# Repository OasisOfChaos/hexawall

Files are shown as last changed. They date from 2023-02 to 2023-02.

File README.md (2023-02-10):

<!-- Improved compatibility of back to top link: See: https://github.com/othneildrew/Best-README-Template/pull/73 -->

<!-- PROJECT LOGO -->
<br />
<div align="center">
  <a href="https://github.com/OasisOfChaos/hexawall">
    
  </a>

<h3 align="center">HexaWall</h3>

  <p align="center">
    <a href="https://github.com/OasisOfChaos/hexawall">GitHub page</a>
  </p>
</div>

<!-- ABOUT THE PROJECT -->
## About The Project

### A pretty big ESP32-driven LED thing for on your wall with about 60 'sequences' you can control via MQTT. 

[Product Name Screen Shot](https://github.com/OasisOfChaos/hexawall)

The dimensions of the thing in this pic are about 1.7m by 0.7m but you can make it as large or small as you'd like.

This repo contains all the different projects to make this thing yourself:
* (PlatformIO) ESP32 firmware (this is a framework with plugin-based 'sequences')
* (Autodesk Inventor) 3D files to print the hexagons
* (Eagle) PCB files
* (Dotnet-Core 6 Blazor) website to control the thing

### Some remarks
* Every hexagon has 30 LEDS.
* I used 12VDC WS2815B ledstrips (BTF-Lighting) but because I used the FastLED library you can use a lot of other addressable strips. 
* I soldered them with separate wires but I'd advice to use the solderless connectors instead. Much easier. You may have to enlarge the hexagon a bit for this though.
* Although the PCB has a provision for powering the ESP I could not get that part to work. Maybe a timing problem or just the power supply I used (a 12V16A supply from AliExpress). In the end I just used a separate power adapter to power the ESP via USB.
* Power the LEDS from TWO sides with a wire large enough for 12VDC/8A. I used 2.5mm2 but it can probably be a bit smaller.
* Some of the sequences are made for this layout specifically. You can follow this one or just remove/rewrite the appropriate sequences.
* The hexagon 'covers' are 3mm acrylate sheets, laser cut.
* Yes, I drilled holes in my wall for the wires and control stuff.

### All this is provided as-is. I will not be able to contribute to this project in the future. Use what you like!

### A Reddit post contains some extra info: (https://www.reddit.com/r/FastLED/comments/10ue1d8/my_hexawall_project/)

<p align="right">(<a href="#readme-top">back to top</a>)</p>

<!-- MARKDOWN LINKS & IMAGES -->
<!-- https://www.markdownguide.org/basic-syntax/#reference-style-links -->
[contributors-shield]: https://img.shields.io/github/contributors/github_username/repo_name.svg?style=for-the-badge
[contributors-url]: https://github.com/github_username/repo_name/graphs/contributors
[forks-shield]: https://img.shields.io/github/forks/github_username/repo_name.svg?style=for-the-badge
[forks-url]: https://github.com/github_username/repo_name/network/members
[stars-shield]: https://img.shields.io/github/stars/github_username/repo_name.svg?style=for-the-badge
[stars-url]: https://github.com/github_username/repo_name/stargazers
[issues-shield]: https://img.shields.io/github/issues/github_username/repo_name.svg?style=for-the-badge
[issues-url]: https://github.com/github_username/repo_name/issues
[license-shield]: https://img.shields.io/github/license/github_username/repo_name.svg?style=for-the-badge
[license-url]: https://github.com/github_username/repo_name/blob/master/LICENSE.txt
[linkedin-shield]: https://img.shields.io/badge/-LinkedIn-black.svg?style=for-the-badge&logo=linkedin&colorB=555
[linkedin-url]: https://linkedin.com/in/linkedin_username
[product-screenshot]: https://github.com/OasisOfChaos/hexawall/blob/main/Images/demo.gif
[Next.js]: https://img.shields.io/badge/next.js-000000?style=for-the-badge&logo=nextdotjs&logoColor=white
[Next-url]: https://nextjs.org/
[React.js]: https://img.shields.io/badge/React-20232A?style=for-the-badge&logo=react&logoColor=61DAFB
[React-url]: https://reactjs.org/
[Vue.js]: https://img.shields.io/badge/Vue.js-35495E?style=for-the-badge&logo=vuedotjs&logoColor=4FC08D
[Vue-url]: https://vuejs.org/
[Angular.io]: https://img.shields.io/badge/Angular-DD0031?style=for-the-badge&logo=angular&logoColor=white
[Angular-url]: https://angular.io/
[Svelte.dev]: https://img.shields.io/badge/Svelte-4A4A55?style=for-the-badge&logo=svelte&logoColor=FF3E00
[Svelte-url]: https://svelte.dev/
[Laravel.com]: https://img.shields.io/badge/Laravel-FF2D20?style=for-the-badge&logo=laravel&logoColor=white
[Laravel-url]: https://laravel.com
[Bootstrap.com]: https://img.shields.io/badge/Bootstrap-563D7C?style=for-the-badge&logo=bootstrap&logoColor=white
[Bootstrap-url]: https://getbootstrap.com
[JQuery.com]: https://img.shields.io/badge/jQuery-0769AD?style=for-the-badge&logo=jquery&logoColor=white
[JQuery-url]: https://jquery.com

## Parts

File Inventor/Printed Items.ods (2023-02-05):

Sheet: Sheet1
Item | Required | Printed | Remaining
Cover v1 - 175 - 12mm rim | 25 | 19 | 6
Base v6 - 175 | 25 | 25 | 0
Flat Placeholder v1 - 175 - 12mm rim - A | 7 | 7 | 0
Flat Placeholder v1 - 175 - 12mm rim - B | 7 | 6 | 1 | 1 damaged

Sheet: Sheet2
1 | 2 | 3 | 4 | 5 | 6 | 7 | 8 | 9
10 | 11 | 12 | 13 | 14 | 15 | 16 | 17 | 18
19 | 20 | 21 | 22 | 23 | 24 | 25 | 26 | 27
1 | 2 | 3 | 4 | 5 | 6 | 7 | 8 | 9
10 | 11 | 12 | 13 | 14 | 15 | 16 | 17 | 18
19 | 20 | 21 | 22 | 23 | 24 | 25 | 26 | 27

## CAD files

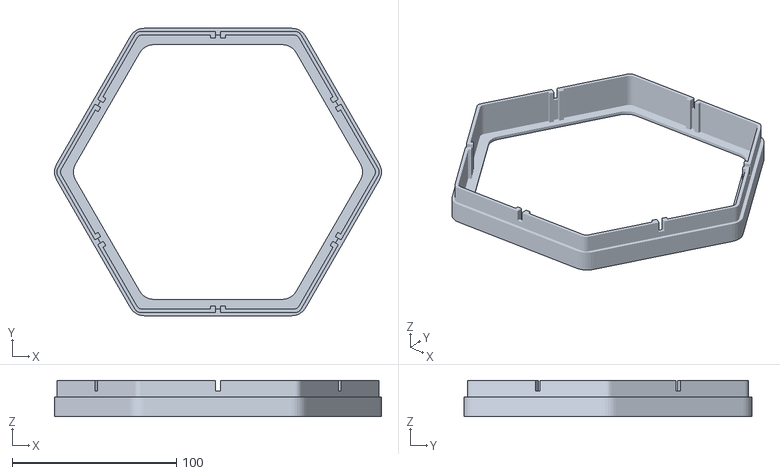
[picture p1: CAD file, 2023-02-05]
Inventor/Cover Adapter v1 - 175.stl
199.0 x 175.0 x 22.0

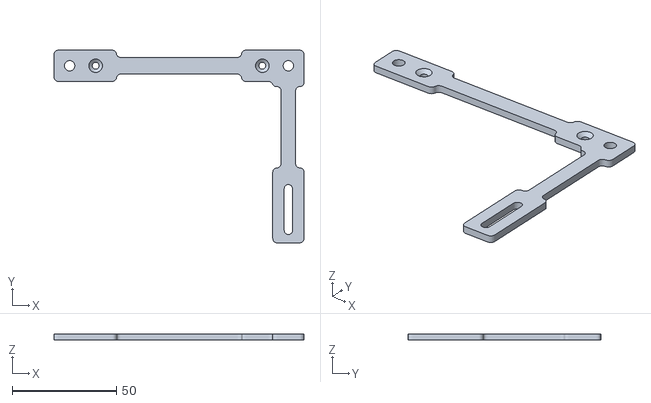
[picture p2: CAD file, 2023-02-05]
Inventor/pcb/Power Supply Wall Mount v3.stl
120.0 x 92.5 x 3.00

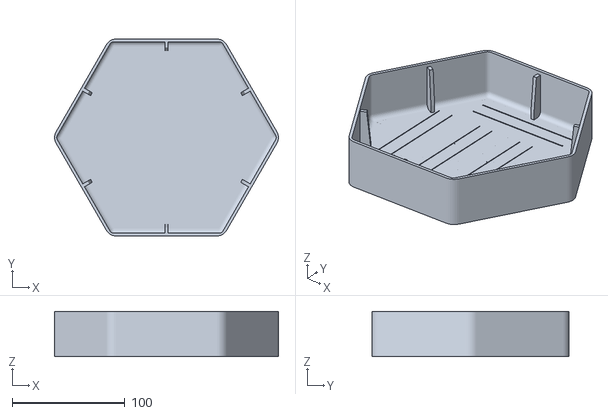
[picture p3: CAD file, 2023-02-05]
Inventor/Base v6 - 175 - thicker wall.stl
199.0 x 175.0 x 40.0

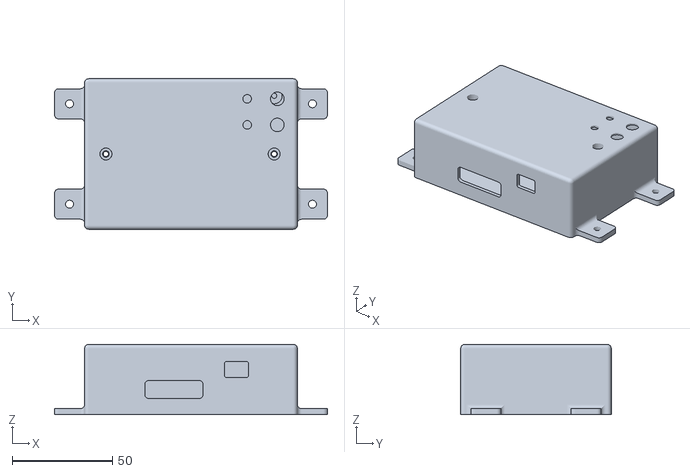
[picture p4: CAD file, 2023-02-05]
Inventor/pcb/Enclosure v1.stl
136.0 x 75.0 x 35.0

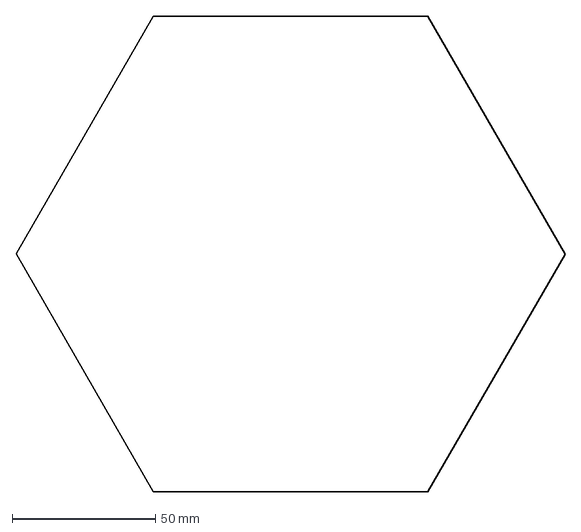
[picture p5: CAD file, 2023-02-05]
Inventor/Frosted Top v1 - 175.dxf
191.7 x 166.0 mm

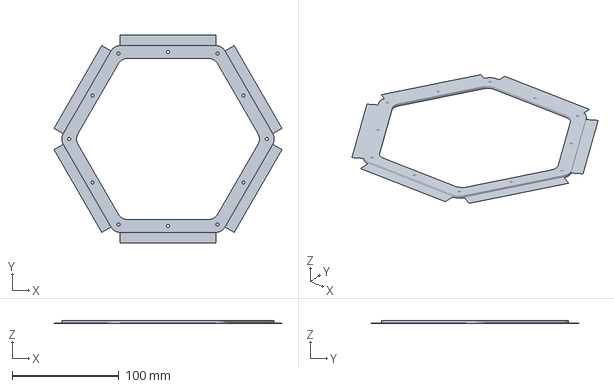
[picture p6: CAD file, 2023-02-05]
Inventor/Flat Placeholder v1 - 175 - 12mm rim.3mf
213.6 x 195.0 x 2.50 mm

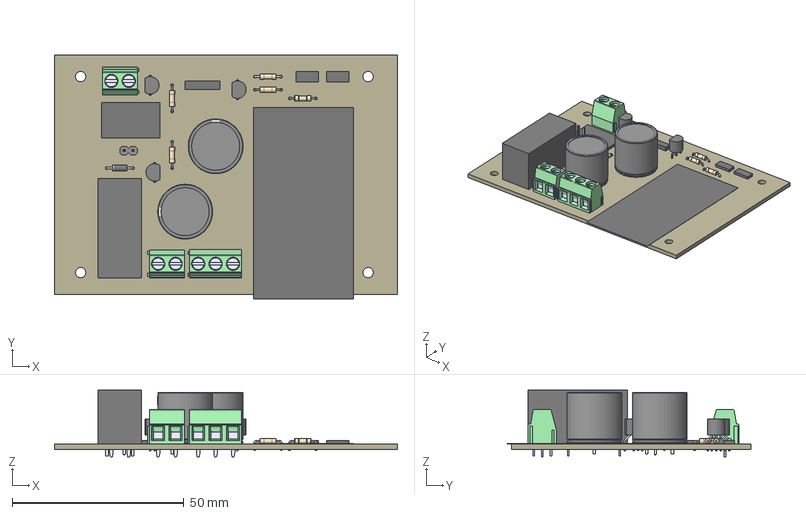
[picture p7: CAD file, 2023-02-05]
Inventor/pcb/HexaWall-v1.1 v7.step
100.0 x 71.2 x 19.5 mm
Board
F/CM12P
DO35-7
DRILEGEND
1X02
G5RL-1-E-HR
0204/7 x 5
DC/DC_PCB
TO92-CBE x 3
E7,5-16 x 2
TB006-508-02P_Green - S
ESP32-DEVKITV1
TB006-508-02P_Green - S (1)
TB006-508-03P_Green - S

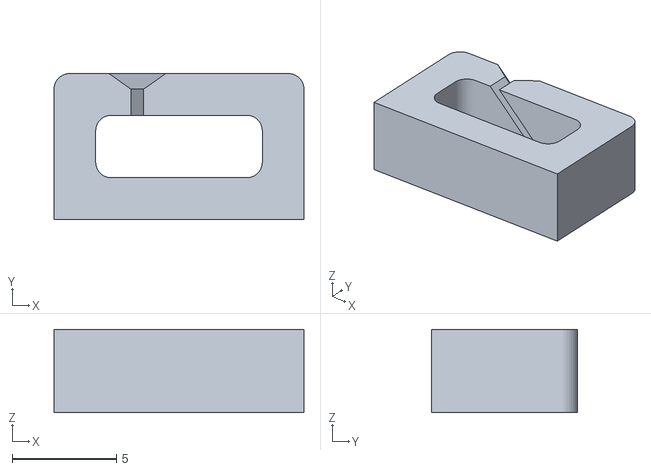
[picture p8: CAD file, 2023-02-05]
Inventor/Cable Clip v3.stl
12.0 x 7.00 x 4.00

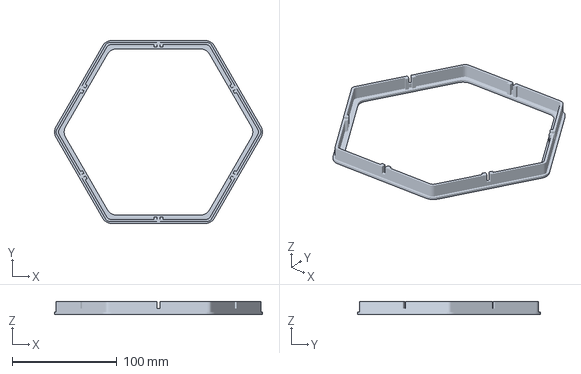
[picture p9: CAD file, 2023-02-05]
Inventor/Cover v1 - 175 - 8mm rim.3mf
199.0 x 175.0 x 12.0 mm

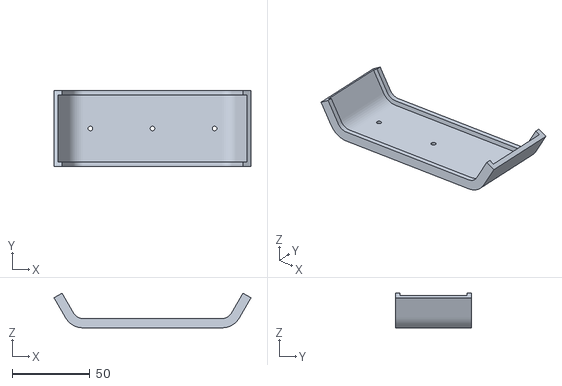
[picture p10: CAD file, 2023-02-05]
Inventor/Drill Helper v1.stl
126.8 x 49.0 x 22.3

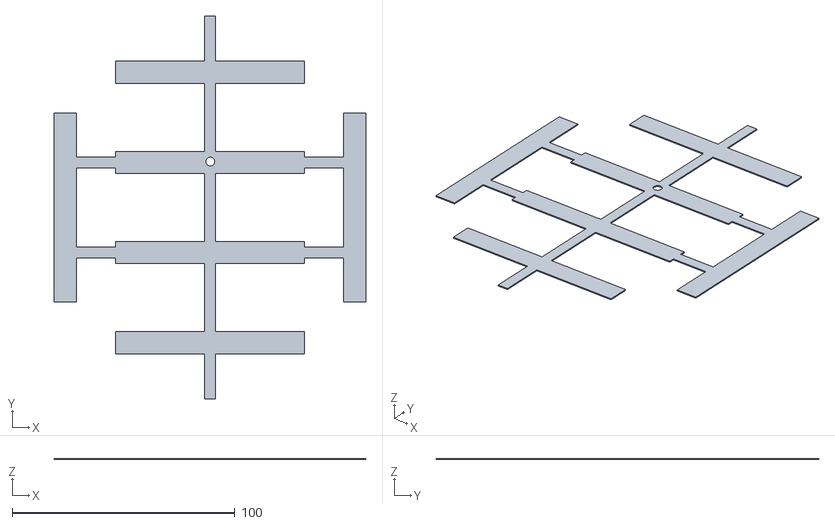
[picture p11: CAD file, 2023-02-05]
Inventor/LED Grid v1.stl
140.0 x 172.0 x 0.5

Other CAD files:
Inventor/Wall Assembly 1600 - 175 - 23 pieces.dwg
Inventor/Wall Assembly 1600 - 175 - 25 pieces - Wall 2 - version A - 0-based.dwg
Inventor/Wall Assembly 1600 - 175 - 25 pieces - version B.dwg
Inventor/Wall Assembly 1600 - 175 - 25 pieces - Wall 2 - version A-.dwg
Inventor/Frosted Top Cutting Helper.dwg
Inventor/Base v6 - 175.stl
Inventor/Paper Cutout v1.dwg
Inventor/Aligner Helper Assembly.iam
Inventor/Aligner Helper v1.ipt
Inventor/Aligner Helper v1.stl
Inventor/Aligner Helper v2.ipt
Inventor/Aligner Helper v2.stl
Inventor/Aligner Helper v3.ipt
Inventor/Aligner Helper v3.stl
Inventor/Base v1 - 150.ipt
Inventor/Base v1.ipt
Inventor/Base v2.ipt
Inventor/Base v3 - 175.ipt
Inventor/Base v3.ipt
Inventor/Base v4 - 175.ipt
Inventor/Base v5 - 175.ipt
Inventor/Base v6 - 175 - thicker wall - Copy.ipt
Inventor/Base v6 - 175 - thicker wall.ipt
Inventor/Base v6 - 175.ipt
Inventor/Base v6 - 88.ipt
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

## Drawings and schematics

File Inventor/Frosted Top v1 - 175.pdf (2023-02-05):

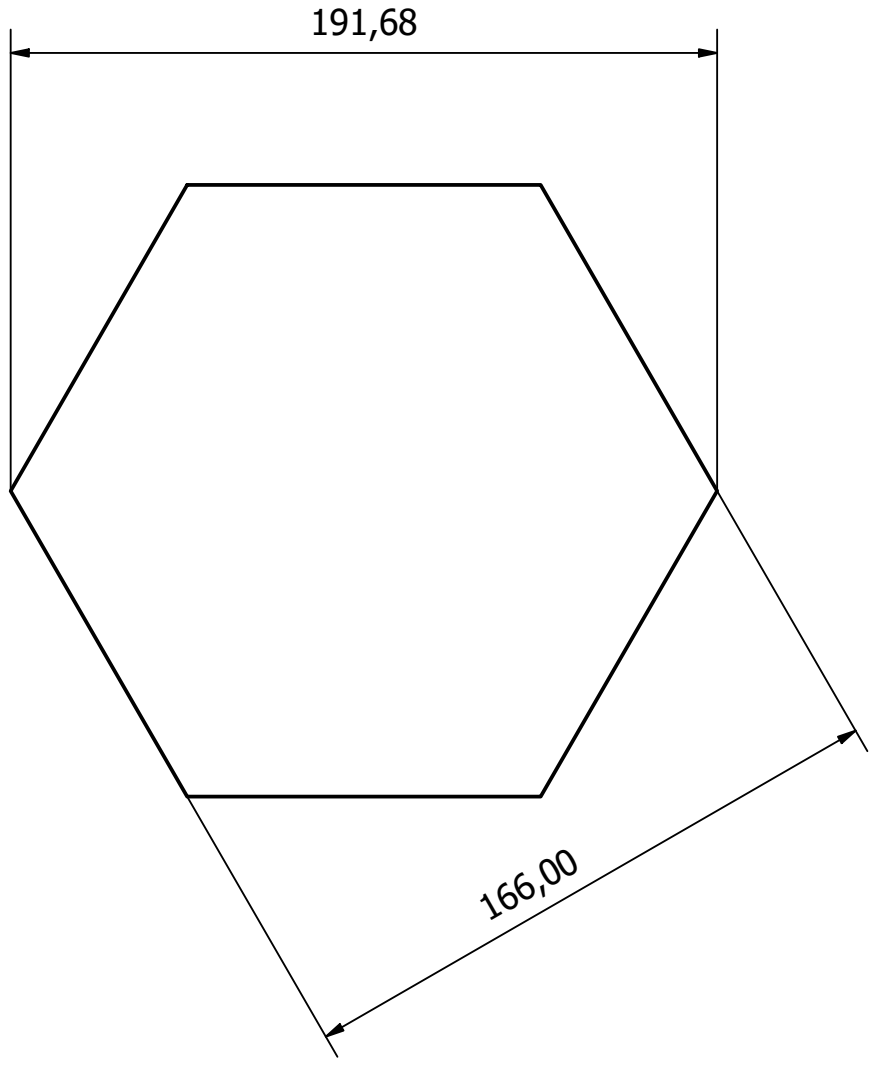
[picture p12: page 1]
Designed by; Checked by; Approved by; Date

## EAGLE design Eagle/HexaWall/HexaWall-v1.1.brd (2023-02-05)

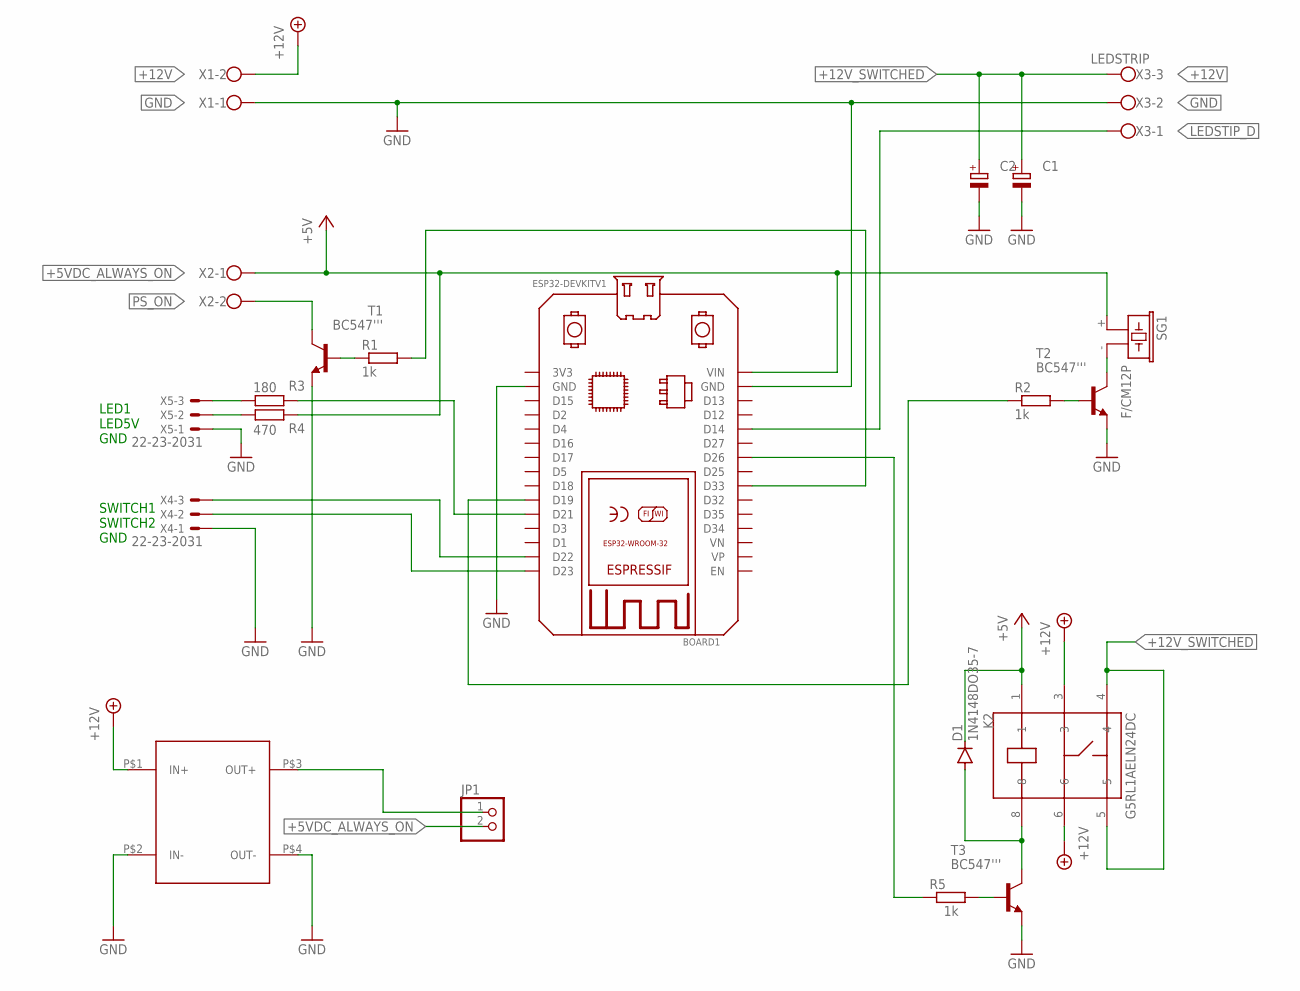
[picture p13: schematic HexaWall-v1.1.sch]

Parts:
BOARD1: ESP32DEVKITV1; ESP32-DEVKITV1
C1, C2: CPOL-EUE7.5-16; E7,5-16
D1: 1N4148DO35-7; DO35-7
JP1: PINHD-1X2; 1X02
K2: G5RL1AELN24DC; G5RL-1-E-HR
PS$1: DC/DC_PCB
R1, R2, R5: 1k; 0204/7
R3: 180; 0204/7
R4: 470; 0204/7
SG1: F/CM12P
T1, T2, T3: BC547'''; TO92-CBE
X1, X2: W237-102
X3: LEDSTRIP; W237-103
X4, X5: 22-23-2031

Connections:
+5VDC_ALWAYS_ON: BOARD1.VIN, D1.C, JP1.2, K2.1, R4.1, SG1.+ (1), X2.1
+12V: K2.3, K2.6, PS$1.P$1 (IN+), X1.2
+12V_SWITCHED: C1.+, C2.+, K2.4, K2.5, X3.3
GND: BOARD1.GND, C1.-, C2.-, PS$1.P$2 (IN-), PS$1.P$4 (OUT-), T1.E, T2.E, T3.E, X1.1, X3.2, X4.1, X5.1
LEDSTIP_D: BOARD1.D14, X3.1
unnamed: R5.2, T3.B
unnamed: R4.2, X5.2
unnamed: R2.2, T2.B
unnamed: BOARD1.D19, R2.1
unnamed: R1.1, T1.B
unnamed: BOARD1.D33, R1.2
unnamed: R3.2, X5.3
unnamed: D1.A, K2.8, T3.C
unnamed: BOARD1.D26, R5.1
unnamed: SG1.- (2), T2.C
unnamed: JP1.1, PS$1.P$3 (OUT+)
unnamed: BOARD1.D22, X4.3
unnamed: BOARD1.D23, X4.2
unnamed: BOARD1.D21, R3.1
PS_ON: T1.C, X2.2

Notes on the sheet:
LED1 LED5V GND
SWITCH1 SWITCH2 GND

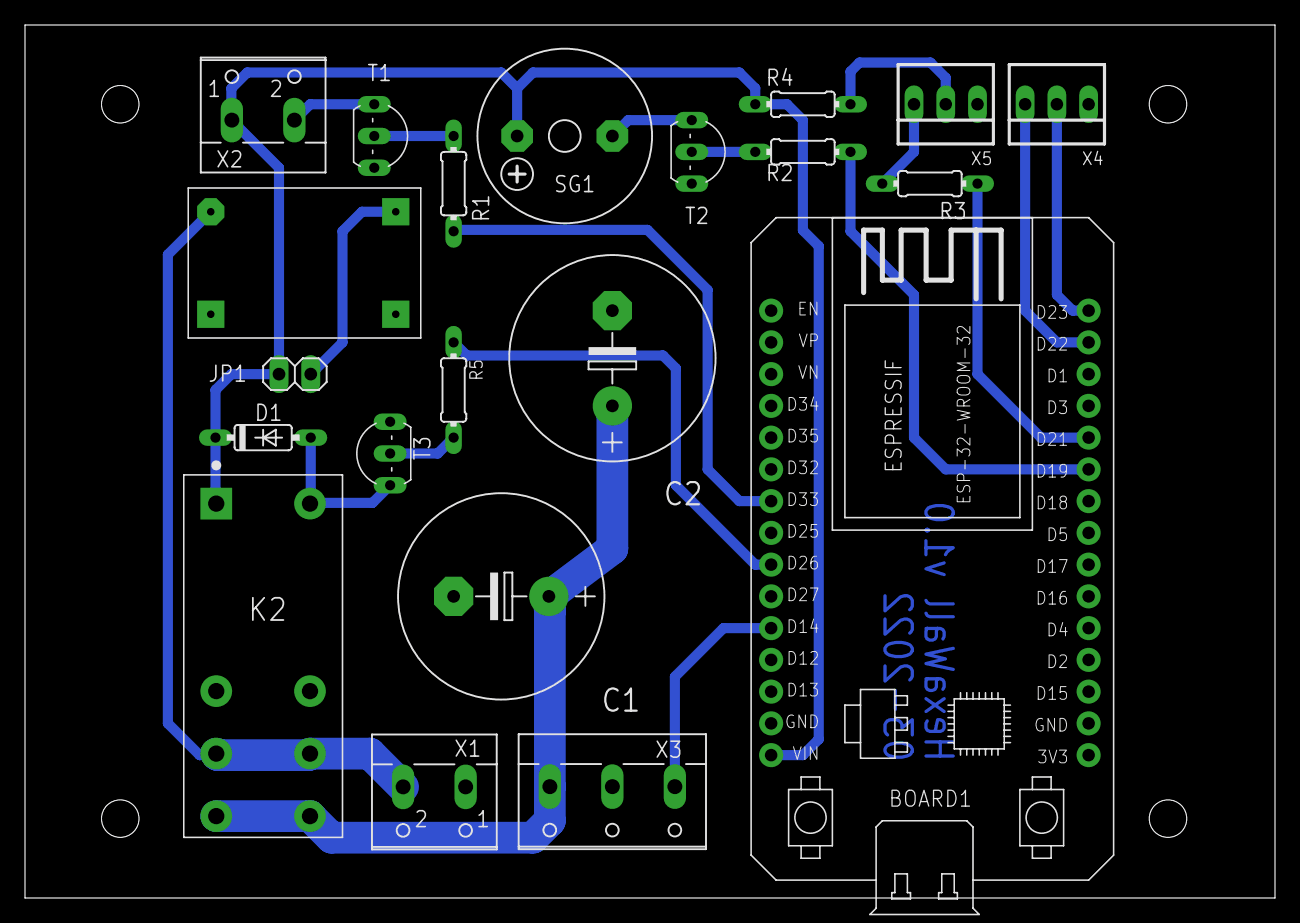
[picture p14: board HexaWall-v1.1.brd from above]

Board: 2 copper layers, 100.0 x 69.8 mm, 22 parts (0 on the bottom side), 20 nets.

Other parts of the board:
DRILEGEND: DRILEGEND

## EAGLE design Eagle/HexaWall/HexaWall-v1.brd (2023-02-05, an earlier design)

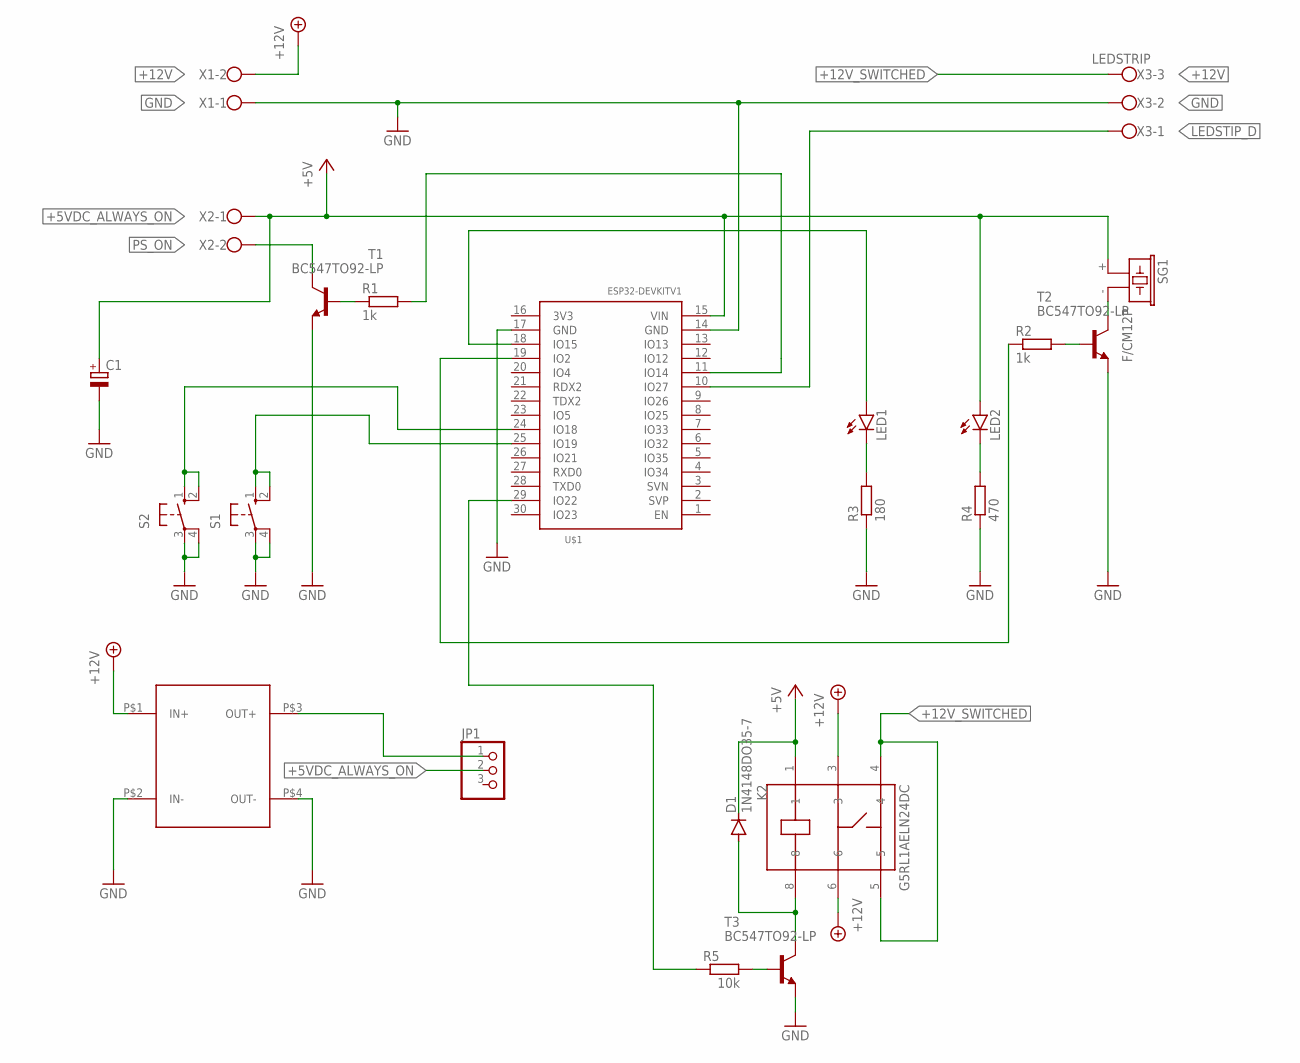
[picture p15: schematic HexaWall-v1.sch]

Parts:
C1: CPOL-EUE10-20; EB20D
D1: 1N4148DO35-7; DO35-7
JP1: PINHD-1X3; 1X03
K2: G5RL1AELN24DC; G5RL-1-E-HR
LED1, LED2: LED5MM
PS$1: DC/DC_PCB
R1, R2: 1k; 0204/7
R3: 180; 0204/7
R4: 470; 0204/7
R5: 10k; 0204/7
S1, S2: 40-XX; B3F-40XX
SG1: F/CM12P
T1, T2, T3: BC547TO92-LP; TO92-CBE
U$1: ESP32DEVKITV1; ESP32-DEVKITV1
X1, X2: W237-102
X3: LEDSTRIP; W237-103

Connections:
+5VDC_ALWAYS_ON: C1.+, D1.C, JP1.2, K2.1, LED2.A, SG1.+ (1), U$1.15 (VIN), X2.1
+12V: K2.3, K2.6, PS$1.P$1 (IN+), X1.2
+12V_SWITCHED: K2.4, K2.5, X3.3
GND: C1.-, PS$1.P$2 (IN-), PS$1.P$4 (OUT-), R3.1, R4.1, S1.3, S1.4 (P1), S2.3, S2.4 (P1), T1.E, T2.E, T3.E, U$1.14 (GND), U$1.17 (GND), X1.1, X3.2
LEDSTIP_D: U$1.10 (IO27), X3.1
unnamed: R5.2, T3.B
unnamed: LED1.K (C), R3.2
unnamed: R2.2, T2.B
unnamed: R2.1, U$1.19 (IO2)
unnamed: R1.1, T1.B
unnamed: R1.2, U$1.11 (IO14)
unnamed: LED2.K (C), R4.2
unnamed: D1.A, K2.8, T3.C
unnamed: R5.1, U$1.29 (IO22)
unnamed: SG1.- (2), T2.C
unnamed: LED1.A, U$1.18 (IO15)
unnamed: JP1.1, PS$1.P$3 (OUT+)
OTA_BUTTON: S2.1 (S), S2.2 (S1), U$1.24 (IO18)
POWER_BUTTON: S1.1 (S), S1.2 (S1), U$1.25 (IO19)
PS_ON: T1.C, X2.2

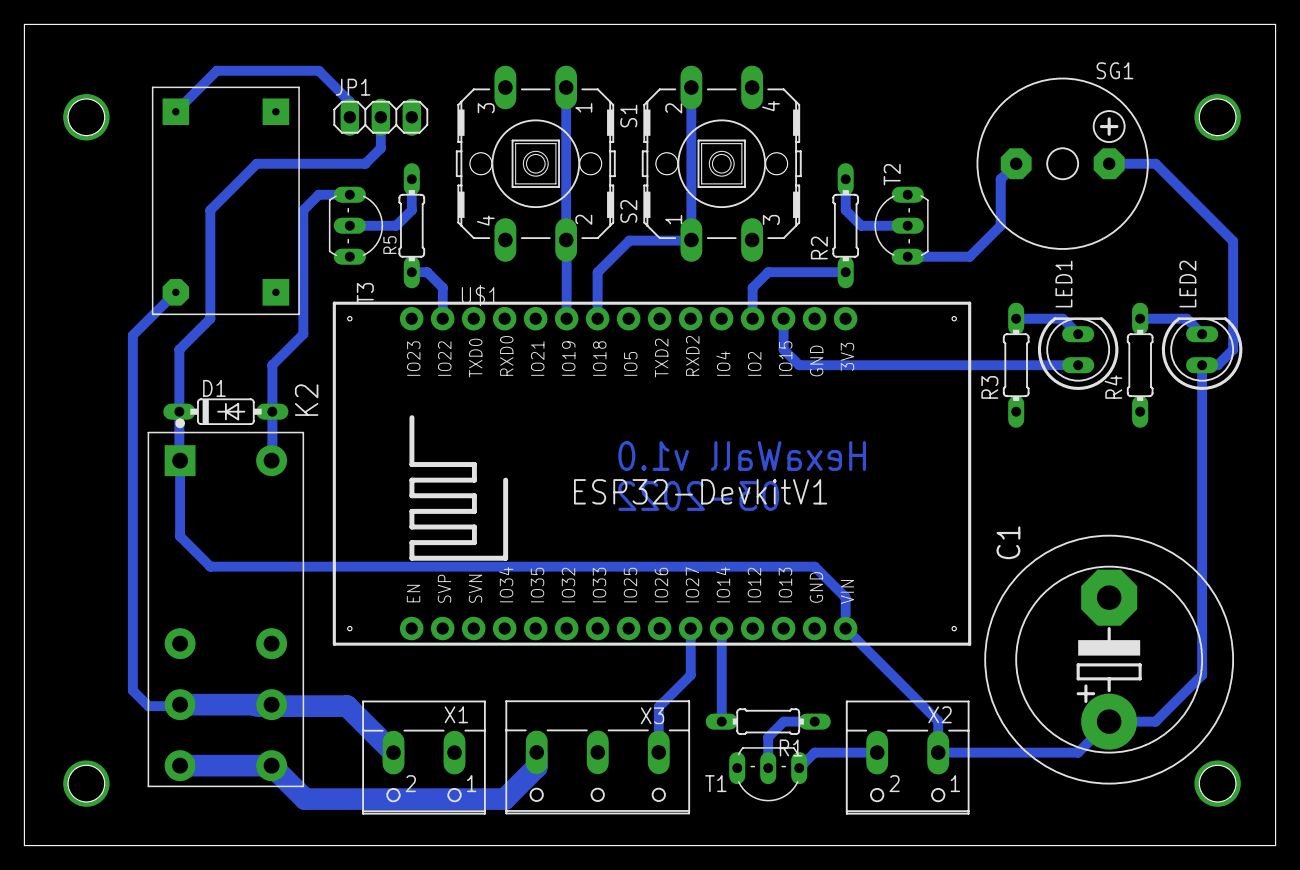
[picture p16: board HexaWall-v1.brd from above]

Board: 2 copper layers, 102.5 x 67.3 mm, 22 parts (0 on the bottom side), 20 nets.

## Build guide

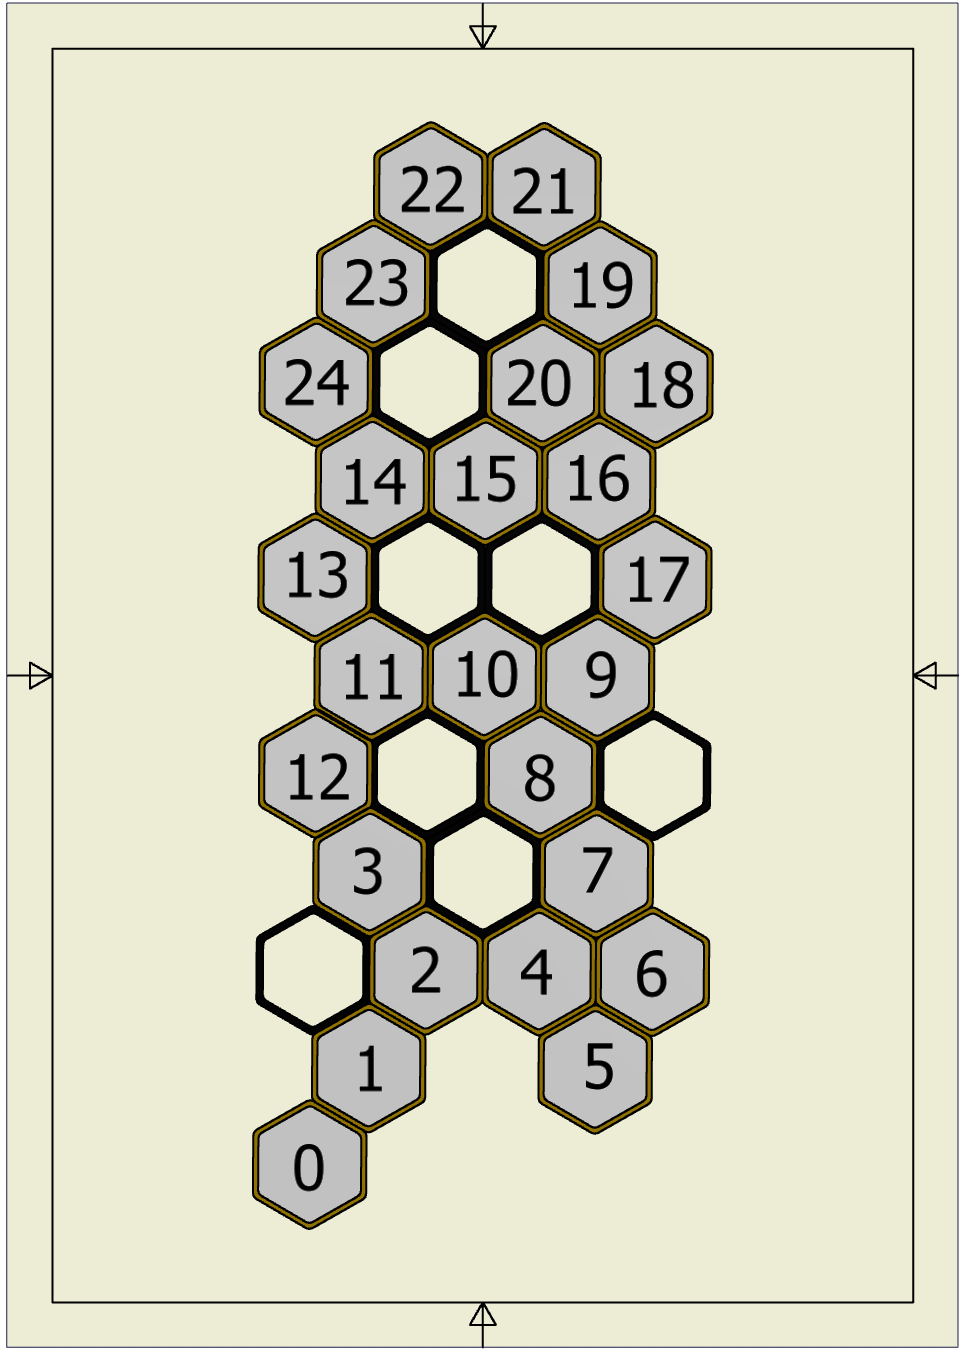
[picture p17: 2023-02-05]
Images/Wall Assembly 1600 - 175 - 25 pieces - Wall 2 - version A - 0-based.bmp

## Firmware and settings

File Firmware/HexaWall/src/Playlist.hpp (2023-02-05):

// Playlist.h

#ifndef _PLAYLIST_h
#define _PLAYLIST_h

#if defined(ARDUINO) && ARDUINO >= 100
#include "arduino.h"
#else
#include "WProgram.h"
#endif

#include "SequenceNames.hpp"
#include <memory>
#include <vector>

using namespace std;

#define DEFAULT_MIN_DURATION 60
#define DEFAULT_MAX_DURATION 240

class PlayList
{
private:
	int _currentPlaylistItemIndex = 999;	//this makes sure the list is randomized after loading

protected:
	std::vector<SequenceName> PlaylistItems;
	int _minimumDurationSeconds = DEFAULT_MIN_DURATION;
	int _maximumDurationSeconds = DEFAULT_MAX_DURATION;

	void randomizeList();

public:
	PlayList();

	SequenceName getNextSequence();
	int getSequenceCount();

	void setMinimumDurationSeconds(int value) { _minimumDurationSeconds = value; }
	void setMaximumDurationSeconds(int value) { _maximumDurationSeconds = value; }

	int getMinimumDurationSeconds() { return _minimumDurationSeconds; }
	int getMaximumDurationSeconds() { return _maximumDurationSeconds; }

	// pure virtual 'abstract' methods
	virtual String getName() = 0;
};

#endif

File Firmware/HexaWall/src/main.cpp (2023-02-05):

#include <Arduino.h>

using namespace std;

#include "settings.hpp"
#include <WiFi.h>
#include "Beeper.hpp"
#include "SequenceManager.hpp"
#include "MQTT.hpp"

SequenceManager sequenceManager;
TimerHandle_t wifiReconnectTimer;
TaskHandle_t doSequenceManagerTaskHandle;
MQTT mqttManager;

CommandPowerState currentPowerState = CommandPowerState::PowerOff;

//function declarations
void Beep(uint8_t pattern);
void doSequenceManagerTask(void *pvParameters);
void setPowerStateFromSeqManager(ManagerPowerState state);
void setPowerStateFromMQTTManager(CommandPowerState state);
void setPowerState(CommandPowerState state, bool notifySeqManager);
void controlPowerIO(bool state);
void WiFiEvent(WiFiEvent_t event);
void startWifi(void);
void checkButtonState(void);
void publishStatusDirect(ManagerStatusTopic topic);
void initIO(void);
void onRebootRequest(void);
void powerStateChangeRequest(CommandPowerState state);


void Beep(uint8_t pattern)
{
  auto beeper = std::unique_ptr<Beeper>(new Beeper(PIN_BEEPER));

  switch (pattern)
  {
  case 0:
    beeper->beep(100, 100);
    beeper->beep(100);
    break;

  case 1:
    beeper->beep(100, 100);
    beeper->beep(100, 100);
    beeper->beep(400);
    break;

  case 2:
    beeper->beep(400, 100);
    beeper->beep(100, 100);
    beeper->beep(100);
    break;

  case 4:
    beeper->beep(100);
  }
}

void doSequenceManagerTask(void *pvParameters)
{
  PRINT_INFO("doSequenceManager: Executing on core: %d.\n", xPortGetCoreID());

  while (true)
  {
    sequenceManager.tick();
  }
}

void setPowerStateFromSeqManager(ManagerPowerState state)
{

  PRINT_INFO("setPowerStateFromSeqManager(): %s\n", state._to_string());

  switch (state)
  {
  case ManagerPowerState::ManagerPowerOff:
    setPowerState(CommandPowerState::PowerOff, false);

    //switch off main power
    controlPowerIO(LOW);
    break;

  case ManagerPowerState::ManagerPoweringOff:
    break;

  case ManagerPowerState::ManagerPowerOn:
    setPowerState(CommandPowerState::PowerOn, false);
    break;

  case ManagerPowerState::ManagerPoweringOn:
    break;

  case ManagerPowerState::ManagerGoingToStandby:
    break;

  case ManagerPowerState::ManagerStandby:
    setPowerState(CommandPowerState::Standby, false);
    break;

  default:
    Beep(0);
    PRINT_INFO("ManagerPowerState: UNKNOWN!\n");
    break;
  }
}

void setPowerStateFromMQTTManager(CommandPowerState state)
{
  setPowerState(state, true);
}

void setPowerState(CommandPowerState state, bool notifySeqManager)
{
  if (currentPowerState == state)
  {
    PRINT_INFO("setPowerState(): ignoring request for '%s' because we're in that state already.\n", state._to_string());
    return;
  }

  currentPowerState = state;

  switch (state)
  {
  case CommandPowerState::PowerOn:
    controlPowerIO(HIGH);
    Beep(4);
    break;

  case CommandPowerState::PowerOff:
    Beep(4);
    break;

  case CommandPowerState::Standby:
    controlPowerIO(HIGH);
    break;

  default:
    Beep(0);
    PRINT_INFO("New powerstate: UNKNOWN!\n");
    break;
  };

  PRINT_INFO("setPowerState(): New powerstate: %s\n", state._to_string());

  if (notifySeqManager)
  {
    sequenceManager.setPowerState(state);
  }
}

void controlPowerIO(bool state)
{
  digitalWrite(PIN_PS_ON, state);
  digitalWrite(PIN_LED_PS_ON, state);
  digitalWrite(PIN_POWER_RELAY, state);

  PRINT_DEBUG("New physical power state: %d.\n", state);
}

void connectToWifi()
{
  WiFi.mode(WIFI_STA);
  WiFi.begin(ssid, password);
  // Serial.print("Connecting to WiFi...");
  // while (WiFi.status() != WL_CONNECTED)
  //{
  //	Serial.print('.');
  //	delay(1000);
  // }
  // Sprintln("");
  PRINT_INFO("Connecting to WiFi...\n");
}

void WiFiEvent(WiFiEvent_t event)
{
  // Sprintf("[WiFi-event] event: %d\n", event);

  switch (event)
  {
  case SYSTEM_EVENT_STA_GOT_IP:
    PRINT_INFO("WiFi connected. IP address: %s\n", WiFi.localIP().toString().c_str());
    /*Serial.print("IP address: ");
    Sprintln(WiFi.localIP());*/
    mqttManager.connect();
    break;

  case SYSTEM_EVENT_STA_DISCONNECTED:
    PRINT_INFO("WiFi lost connection.\n");

    // ensure we don't reconnect to MQTT while reconnecting to Wi-Fi
    mqttManager.stopReconnectTimer();
    // xTimerStop(mqttReconnectTimer, 0); // ensure we don't reconnect to MQTT while reconnecting to Wi-Fi

    xTimerStart(wifiReconnectTimer, 0);
    break;
  }
}

void startWifi(void)
{
  // mqttReconnectTimer = xTimerCreate("mqttTimer", pdMS_TO_TICKS(2000), pdFALSE, (void*)0, reinterpret_cast<TimerCallbackFunction_t>(connectToMqtt));
  wifiReconnectTimer = xTimerCreate("wifiTimer", pdMS_TO_TICKS(2000), pdFALSE, (void *)0, reinterpret_cast<TimerCallbackFunction_t>(connectToWifi));

  WiFi.onEvent(WiFiEvent);

  // initMqtt();
  connectToWifi();
}

void checkButtonState(void)
{
  if (digitalRead(PIN_PUSHBUTTON1) == 0)
  {
    // debounce
    delay(1000);

    if (digitalRead(PIN_PUSHBUTTON1) == 0)
    {
      if (currentPowerState == +CommandPowerState::PowerOn)
      {
        setPowerState(CommandPowerState::PowerOff, true);
      }
      else
      {
        setPowerState(CommandPowerState::PowerOn, true);
      }
    }
  }
}

void publishStatusDirect(ManagerStatusTopic topic)
{
  if (!mqttManager.isInitialized() || !mqttManager.isConnected())
  {
    return;
  }

  PRINT_DEBUG("Received a publishStatus for topic '%s'.\n", topic._to_string());

  switch (topic)
  {
  case ManagerStatusTopic::StatusTopicPowerState:
    mqttManager.publishDeviceState();
    break;
  case ManagerStatusTopic::StatusTopicBrightness:
    mqttManager.publishLEDBrightness();
    break;
  case ManagerStatusTopic::StatusTopicSequence:
    mqttManager.publishLEDProgram();
    break;
  case ManagerStatusTopic::StatusTopicSolidColor:
    mqttManager.publishLEDRGBColor();
    break;
  case ManagerStatusTopic::StatusTopicPilotLight:
    mqttManager.publishPilotLight();
    break;
  case ManagerStatusTopic::StatusTopicPlaylist:
    mqttManager.publishActivePlaylist();
    break;
  case ManagerStatusTopic::StatusTopicPlaylistDuration:
    mqttManager.publishLEDProgramDuration();
    break;
  case ManagerStatusTopic::StatusTopicInternalLEDBlink:
    mqttManager.publishOSBlinkLEDState();
    break;
  default:
    break;
  }
}

void initIO(void)
{
  controlPowerIO(false);

  pinMode(PIN_PS_ON, OUTPUT);
  pinMode(PIN_LED_PS_ON, OUTPUT);
  pinMode(PIN_POWER_RELAY, OUTPUT);
  pinMode(PIN_PUSHBUTTON1, INPUT_PULLUP);
}

void onRebootRequest(void)
{
  ESP.restart();
}

void powerStateChangeRequest(CommandPowerState state)
{
  PRINT_INFO("MQTT powerStateChangeRequest for state: %d\n", state);
}

void setup(void)
{
  Serial.begin(115200);

  PRINT_DEBUG("\nCompiler version:%ld\n", __cplusplus);
  PRINT_INFO("Setup/Loop: Executing on core: %d.\n", xPortGetCoreID());

  initIO();

  startWifi();

  sequenceManager.onStatusChange(publishStatusDirect);
  sequenceManager.onPowerStateChange(setPowerStateFromSeqManager);

  mqttManager.onPowerStateChange(setPowerStateFromMQTTManager);
  mqttManager.onRebootRequest(onRebootRequest);

  sequenceManager.init();

  mqttManager.init(&sequenceManager);

  // set random seed to a 'real' random number
  random16_set_seed(esp_random());

  // xTaskCreatePinnedToCore(
  //	doSequenceManagerTask,   /* Function to implement the task */
  //	"doSequenceManagerTask", /* Name of the task */
  //	40000,      /* Stack size in words */
  //	NULL,       /* Task input parameter */
  //	20,          /* Priority of the task */
  //	&doSequenceManagerTaskHandle,       /* Task handle. */
  //	0);  /* Core where the task should run */

  Beep(0);

  PRINT_INFO("Intializing done. Ready.\n");

#ifdef DEVELOP_MODE
  setPowerState(CommandPowerState::PowerOn, true);

  // sequenceManager.enableInternalLEDBlink(true);
  // sequenceManager.setLEDBrightness(255, false);
  // sequenceManager.enableRandomCycle(true);

  // sequenceManager.setLEDSolidColor(CRGB(0, 0, 255));
  // sequenceManager.setLEDSolidColor(CRGB(255, 0, 0));
  // sequenceManager.setLEDBrightness(50, true);
  // sequenceManager.setSequence(SequenceName::CyclePrimaryColors);
  // sequenceManager.setSequence(SequenceName::None);
  // sequenceManager.setSequence(SequenceName::ColumnTest);

  sequenceManager.loadPlayList(1);	//all of them
  // sequenceManager.loadPlayList(2);	//flows
#endif
}

void loop(void)
{
  sequenceManager.tick();

  checkButtonState();
}

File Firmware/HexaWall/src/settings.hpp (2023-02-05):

#pragma once

#ifndef _SETTINGS_H
#define _SETTINGS_H

//#define DEVELOP_MODE
#define ENABLE_SERIAL_PRINT_INFO
//#define ENABLE_SERIAL_PRINT_DEBUG

const char* const ssid = "OasisOfChaos_";
const char* const password = "pyY5v6kCHYAs3FEJ";

#define MQTT_HOST IPAddress(192, 168, 0, 1)
#define MQTT_PORT 1883

const char* const mqtt_user = "admin";
const char* const mqtt_password = "MqTT5634!";

#define LED_BUILTIN			2
#define PIN_BEEPER			19
#define PIN_IR_RECEIVER		22
#define PIN_OTA_BUTTON		22
#define PIN_PS_ON		    33
#define PIN_LED_PS_ON		21
#define PIN_PUSHBUTTON1		23
#define PIN_POWER_RELAY		26

//#define LED_PIN             14
//#define LED_TYPE            WS2812B
//#define COLOR_ORDER         GRB
//#define LED_COUNT           750

#ifdef ENABLE_SERIAL_PRINT_INFO
#define PRINT_INFO_0() (Serial.printf())
#define PRINT_INFO_1(a) (Serial.printf(a))
#define PRINT_INFO_2(a, b) (Serial.printf(a, b))
#define PRINT_INFO_3(a, b, c) (Serial.printf(a, b, c))
#define PRINT_INFO_4(a, b, c, d) (Serial.printf(a, b, c, d))
#else
#define PRINT_INFO_0()
#define PRINT_INFO_1(a)
#define PRINT_INFO_2(a, b)
#define PRINT_INFO_3(a, b, c)
#define PRINT_INFO_4(a, b, c, d)
#endif

#ifdef ENABLE_SERIAL_PRINT_DEBUG
#define PRINT_DEBUG_0() (Serial.printf())
#define PRINT_DEBUG_1(a) (Serial.printf(a))
#define PRINT_DEBUG_2(a, b) (Serial.printf(a, b))
#define PRINT_DEBUG_3(a, b, c) (Serial.printf(a, b, c))
#define PRINT_DEBUG_4(a, b, c, d) (Serial.printf(a, b, c, d))

#else
#define PRINT_DEBUG_0()
#define PRINT_DEBUG_1(a)
#define PRINT_DEBUG_2(a, b)
#define PRINT_DEBUG_3(a, b, c)
#define PRINT_DEBUG_4(a, b, c, d)
#endif

// The interim macro that simply strips the excess and ends up with the required macro
#define PRINT_INFO_X(x,a,b,c,d,FUNC, ...)  FUNC
#define PRINT_DEBUG_X(x,a,b,c,d,FUNC, ...)  FUNC

// The macro that the programmer uses
#define PRINT_INFO(...)                   PRINT_INFO_X(,##__VA_ARGS__,\
                                          PRINT_INFO_4(__VA_ARGS__),\
                                          PRINT_INFO_3(__VA_ARGS__),\
                                          PRINT_INFO_2(__VA_ARGS__),\
                                          PRINT_INFO_1(__VA_ARGS__),\
                                          PRINT_INFO_0(__VA_ARGS__)\
                                          )

#define PRINT_DEBUG(...)                  PRINT_DEBUG_X(,##__VA_ARGS__,\
                                          PRINT_DEBUG_4(__VA_ARGS__),\
                                          PRINT_DEBUG_3(__VA_ARGS__),\
                                          PRINT_DEBUG_2(__VA_ARGS__),\
                                          PRINT_DEBUG_1(__VA_ARGS__),\
                                          PRINT_DEBUG_0(__VA_ARGS__)\
                                          )
#endif
